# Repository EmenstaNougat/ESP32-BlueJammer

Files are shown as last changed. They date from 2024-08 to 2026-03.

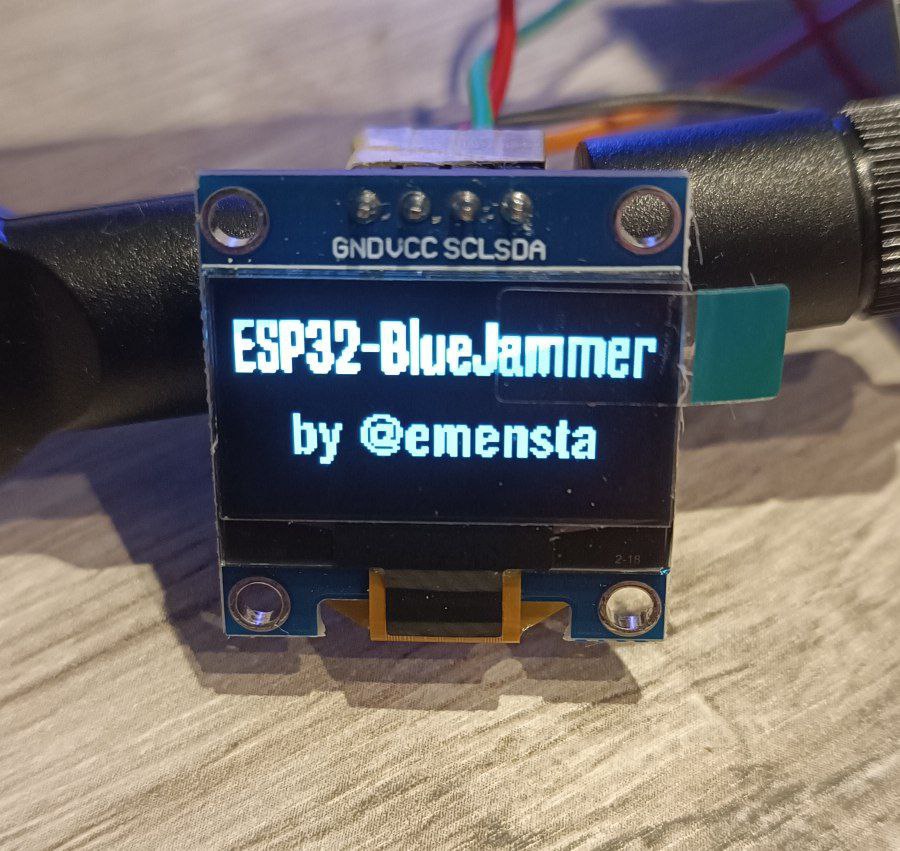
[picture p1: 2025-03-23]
Gallery/ESP32-BlueJammerOLED.jpg

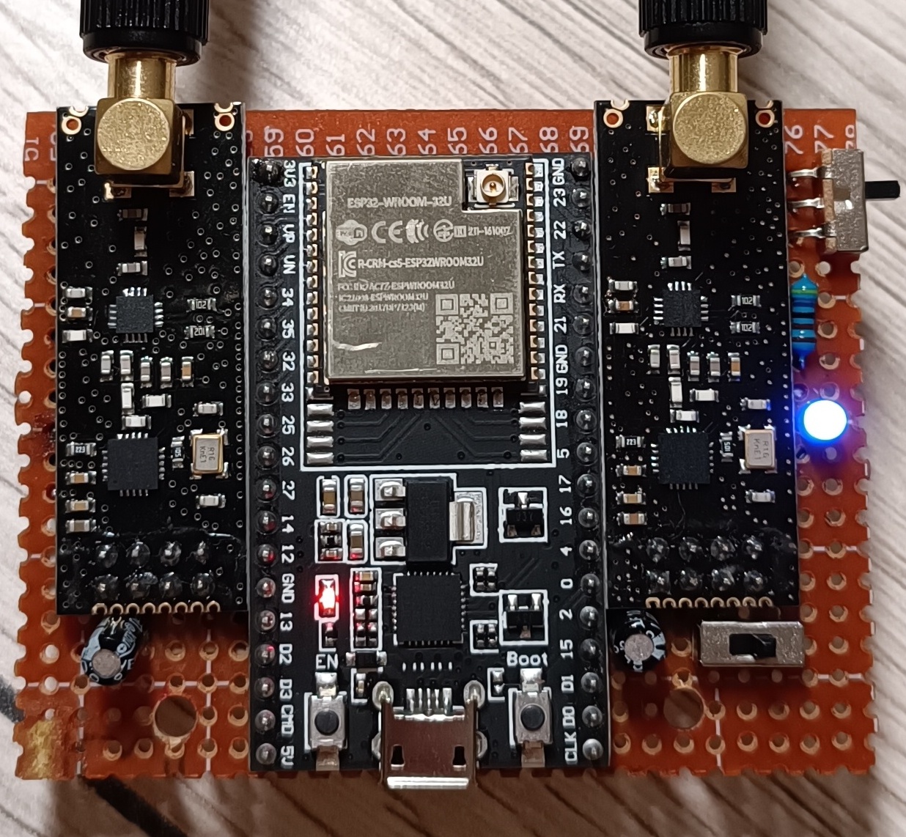
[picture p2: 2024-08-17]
Gallery/PrototypePCB.jpg

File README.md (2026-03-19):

<h1 align="center">ESP32-BlueJammer - by @emensta</h1>
<div align="center">
  ESP32-BlueJammer
  <h3 align="center">Jamming is ILLEGAL! Educational purposes only!</h3>
  <h3 align="center"><a href="https://github.com/EmenstaNougat/BlueJammer-V2">BlueJammer-V2</a>, <a href="https://github.com/EmenstaNougat/BW16-BlueJammer">BW16-BlueJammer</a> & <a href="https://github.com/EmenstaNougat/ZeroWave_FlipperZero-BlueJammer">ZeroWave for Flipper Zero</a> released!</h3>
</div>

<div align="center">
<a href="https://github.com/EmenstaNougat/ESP32-BlueJammer" title="Go to GitHub repo">
  
</a>
<a href="https://github.com/EmenstaNougat/ESP32-BlueJammer">
  
</a>
<a href="https://github.com/EmenstaNougat/ESP32-BlueJammer">
  
</a>
</div>

<h4 align="center">
  <a href="https://github.com/EmenstaNougat/ESP32-BlueJammer#hardware---make-your-own-esp32-bluejammer">Make your own</a>
    <span> | </span>
  <a href="https://github.com/EmenstaNougat/ESP32-BlueJammer#esp32-nrf24l01-pinout--battery-mod">Schematics</a>
    <span> | </span>
  <a href="https://github.com/EmenstaNougat/ESP32-BlueJammer?tab=readme-ov-file#pcb">Hardware layout</a>
    <span> | </span>
  <a href="https://github.com/EmenstaNougat/ESP32-BlueJammer?tab=readme-ov-file#pcbs-with-esp32-and-rf-module-capability">PCB's</a>
    <span> | </span>
  <a href="https://github.com/EmenstaNougat/ESP32-BlueJammer#video-tutorials-and-demonstrations">Demos</a>
    <span> | </span>
  <a href="https://github.com/EmenstaNougat/ESP32-BlueJammer#operation-channels">Channels</a>
    <span> | </span>
  <a href="https://github.com/EmenstaNougat/ESP32-BlueJammer?tab=readme-ov-file#flashing-the-firmware">Flashing</a>
    <span> | </span>
  <a href="https://github.com/EmenstaNougat/ESP32-BlueJammer#3d-printed-case">3D case</a>
    <span> | </span>
  <a href="https://github.com/EmenstaNougat/ESP32-BlueJammer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">About</a>
    <span> | </span>
  <a href="https://github.com/EmenstaNougat/ESP32-BlueJammer?tab=readme-ov-file#support-me">Support me</a>
    <span> | </span>
  <a href="https://emensta.pages.dev">Website</a>
</h4>

## ESP32-BlueJammer
The ESP32-BlueJammer (Bluetooth jammer, BLE jammer, WiFi jammer, RC jammer) disrupts various devices using an ESP32 and nRF24 modules, causing plenty of noise and sending unnecessary packets (DoS).              
                                                                    
It interrupts:  
**The whole 2.4GHz broadband!** Everything that works on 2.4GHz is being interfered, like:                                                       
audio in speakers being transmitted over bluetooth, microphones on 2.4GHz, smartphone connections, WiFi, RC Drones (etc.), IoT devices, smart gadgets, wireless keyboard & mouse, just anything on 2.4GHz!

Ideal for controlled disruption and security testing. Based on 2.4GHz communication.

It has a big range (over 30Meters+ - may vary on your antenna and hardware setup!) on newest Bluetooth versions with casual 2.4GHz antennas, you can easily increase this as well by taking some simple "bigger" router antennas.
An amplifier (2.4GHz) may be a good option too!

Remember that jamming is illegal and should not be used with malicious intent!

## PCB's with ESP32 and RF-module capability
**ESP32-RF DIY-PCB:**
This PCB can fit an ESP32-wroom-32U/E DevKitC and 2 nRF-modules, along with an 0.96" I2C OLED, LEDs and switches.  
***Remember: It is not intended for illegal use!***  
For this one, all you need is listed below:  

**Required:**  
- **[ESP32 Dev Module](https://s.click.aliexpress.com/e/_onYIVKr)** (**Recommended: ESP32-32U CP2102**, any ESP32 should work as long as it has the needed pins, 38P required!)  
- **[nRF24L01+PA+LNA](https://s.click.aliexpress.com/e/_oma5UQx)** (2x)  
- **[10-100uF Capacitor](https://s.click.aliexpress.com/e/_oFvFeYX)** (2x) (any voltage above 5V)  
- **[0.96" OLED Display I2C](https://s.click.aliexpress.com/e/_oCdkjPX)**
- **[Slide Switch](https://s.click.aliexpress.com/e/_c4eQKm5D)** (2x)
- **[LEDs: 3mm LED box](https://s.click.aliexpress.com/e/_c4dAH9sF)**  
- **[Resistor kit](https://s.click.aliexpress.com/e/_oCoJ7LO)**  
- R1 = 1kOhm  
- R2, R3, R5, R7 = 47kOhm  
- R4, R6 = 100kOhm  

**Additional:**  
- **[TP4056 Charging Module (Micro-USB/Type-C)](https://s.click.aliexpress.com/e/_oCqORHE)**  
- **[JST PH 2.0 Connector](https://s.click.aliexpress.com/e/_ooSOhDd)**  
- **[3.7V Li-Ion Battery](https://s.click.aliexpress.com/e/_on04mQ7)**  
- **[3rd Antenna: **IPEX to SMA-F pigtail](https://s.click.aliexpress.com/e/_oFDpn1V)**  
  
[Shop](https://www.elecrow.com/esp32-rf-diy-pcb.html)

---

**PRE-SOLDERED:**  "The Blue ESP"  
This is an ESP32 with RF-module breakouts (nRF24/CC1101 etc.) for experimenting.  
***Remember: It is not intended for illegal use, neither for my project!***  

**Required:**  
- **[nRF24L01+PA+LNA](https://s.click.aliexpress.com/e/_oma5UQx)** (2x)  
Why do you need to get the nRF24's? -> the pinout can be used to connect either nRF24 or CC1101 modules for further experiments with an ESP32 chip.
TheBlueESP
[Shop](https://datechlabs.com/products/the-blue-esp-pre-order)

## Video tutorials and demonstrations
[Full DIY assembling video tutorial](https://www.tiktok.com/@emensta/video/7389783018002550049)

[Full DIY assembling video tutorial (if the TikTok is not available for you)](https://www.mediafire.com/file/mgb3wicdifkq1ce/ESP32-BlueJammerByEmensta-DIYTutorial.mp4/file)

---

[Demonstration](https://vm.tiktok.com/ZGec5Mqg7/)

[Demonstration (if the TikTok is not available for you)](https://www.mediafire.com/file/xgru01ihbw26mfu/ESP32-BlueJammerByEmensta-Demonstration.mp4/file)

---

[Flashing process](https://www.tiktok.com/@emensta/video/7413509704401292577)

[Flashing process (if the TikTok is not available for you)](https://www.mediafire.com/file/2aj4hmf9zt7w6sw/ESP32-BlueJammerByEmensta-FlashingProcess.mp4/file)

---

ESP32-BlueJammer tutorial by @ElMackflay  
ESP32-BlueJammer tutorial by @ElMackflay (https://www.youtube.com/watch?v=1kjkWU25_qo)  
---

## Operation Channels
- **Bluetooth** = 79CH  
  Frequency Range: 2.402 GHz to 2.480 GHz  
  Channel Width: 1 MHz

- **BLE** = 40CH  
  Frequency Range: 2.400 GHz to 2.4835 GHz  
  Channel Width: 2 MHz

- **WiFi** = 14CH  
  Frequency Range: 2.400 GHz to 2.4835 GHz  
  Channel Width: Typically 20 MHz, but can be 22 MHz or 40 MHz in some cases

- **RC drones, etc.** = 1-125CH  
  Frequency Range: 2.400 GHz to 2.525 GHz  
  Channel Width: 1 MHz

## How to use?
To disrupt various channels on the 2.4GHz band, do the following to enable your ESP32-BlueJammer:
- Every mode starts right away after powering on the device! There is no additional button to start the attack!  
- It simply jams right away once powered!

### Combo-Channel-Select_BT-BLE-WiFi-RC firmware:
- use the "Boot" button on the ESP32 to switch between the channel modes on the Combo-Firmware!
- the OLED will display your current operation channel
- the status LED lets you know about the current state you're in:  
1 blink = BT  
2 blinks = BLE  
3 blinks = WiFi  
4 blinks = RC  
- the serial output of your ESP32-BlueJammer will output the following lines when switching mode:  
State 1: Bluetooth  
State 2: Bluetooth Low Energy  
State 3: WiFi  
State 4: RC  

### all other firmware:
- the firmware you choose indicates the operation channel by its name, this means:

Bluetooth_80_CH - jams classic Bluetooth  
Frequency Range: 2.402 GHz to 2.480 GHz  

BluetoothLowEnergy_40_CH - jams Bluetooth Low Energy  
Frequency Range: 2.400 GHz to 2.4835 GHz  

Bluetooth-BluetoothLowEnergy_40-80_CH - jams classic Bluetooth & Bluetooth Low Energy  
Frequency Range: 2.402 GHz to 2.480 GHz & 2.400 GHz to 2.4835 GHz  

Bluetooth-WiFi_14-80_CH - jams classic Bluetooth & WiFi  
Frequency Range: 2.402 GHz to 2.480 GHz & 2.400 GHz to 2.4835 GHz  

WiFi_14_CH - jams WiFi  
Frequency Range: 2.400 GHz to 2.4835 GHz  

2.4GHzRemoteControl(Drones etc.)_1-125_CH - jams RC (Drones etc.)  
  Frequency Range: 2.400 GHz to 2.525 GHz  

## Hardware - Make your own ESP32-BlueJammer
(Aliexpress affiliate links to support me-linked to the item names)
### Required:

- **[ESP32 Dev Module](https://s.click.aliexpress.com/e/_onYIVKr)** (**Recommended: ESP32-32U CP2102**, any ESP32 should work as long as it has the needed pins)
- **[nRF24L01+PA+LNA](https://s.click.aliexpress.com/e/_oma5UQx)** (2x)
- **[10-100uF Capacitor](https://s.click.aliexpress.com/e/_oFvFeYX)** (2x) (any voltage above 5V)
- **[Prototype PCB](https://s.click.aliexpress.com/e/_oBtd18j)** (at least 7x9 cm, but you will need to cut it down to fit the 3D-printed case, which fits a size of 7x5,5cm!)

### Additional:

- **[0.96" OLED Display I2C](https://s.click.aliexpress.com/e/_oCdkjPX)**
- [3rd Antenna: **IPEX to SMA-F pigtail**](https://s.click.aliexpress.com/e/_oFDpn1V)
- [Status LED: **3mm LED**](https://s.click.aliexpress.com/e/_ooxufHV)
- **[4.7k Ohm Resistor](https://s.click.aliexpress.com/e/_oBV1Q1Z)**

### If you're looking to add a battery:

- **[3.7V Li-Ion Battery](https://s.click.aliexpress.com/e/_on04mQ7)**
- **[JST PH 2.0 Connector](https://s.click.aliexpress.com/e/_ooSOhDd)**
- **[TP4056 Charging Module (Micro-USB/Type-C)](https://s.click.aliexpress.com/e/_oCqORHE)**
- **[Mini Slide Switch](https://s.click.aliexpress.com/e/_ooC8DXh)**

### To screw the 3D printed case together you must have:

- **M3x16 Screws** (2x)  
- **M3 Nuts** (2x)  
Get this M3 kit instead:
- **[M3 screws&nuts kit](https://s.click.aliexpress.com/e/_oC24YXH)**

## Antennas
A frequently asked question is whether the antennas are needed and what the third antenna is for, here is the answer:
Yes, you need at least both antennas for the nRF24's! Why? To have it working on a decent range!
The average range with standard known chinese 2.4GHz antennas is about 20-30meters. Upgrading those antennas will help a lot with getting more range!

2 antennas are for the HSPI and VSPI nRF24 modules!

The 3rd antenna is plugged to the ESP32 chip itself, whether via IPEX or soldered onto its own antenna, if your ESP32 does not provide any option to add that one, it obviously won't be possible!
What is the 3rd antenna used for? The third antenna connected to the ESP32 chip itself helps with reliable long-range interference. It ensures a better intermediate signal and stability when jamming!
(The third antenna is your own decision and therefore optional!)

## Flashing the firmware
### via webflasher (Easy)  
ESP32-BlueJammerFlasher                                                                 
I've created a webflasher to make it super easy for you to flash your ESP32 chip with the ESP32-BlueJammer firmware of your choice!  
- Visit [ESP32-BlueJammerFlasher](https://esp32-bluejammerflasher.pages.dev)
- First, choose the firmware type, "Generic" or "0.96" OLED"
- choose the firmware you want to flash
- Connect your ESP32 via a data USB cable
- Flash the firmware of your choice :D

### Flashing ESP32 via binary files (Advanced)  
- Download the **.bin files** available on this repository
- Use any flasher of your choice
- Flash it :D

If your ESP32 is not showing up in the device list or won't get recognized you will need to have [THESE DRIVERS INSTALLED](https://www.silabs.com/documents/public/software/CP210x_Windows_Drivers.zip) which can be found on my [Discord server](https://discord.gg/yNGhKxzqUE) too!

## ESP32-nRF24L01+ pinout + battery mod
Here are both pinouts for HSPI and VSPI. You need both nRF24L01 modules connected in order to achieve full capability of the device.                
[nRF24L01+ pinout](https://dwdwpld.pages.dev/nRF24L01pinout.png)
### HSPI
| 1st nRF24L01 module Pin | HSPI Pin (ESP32) | 10uf capacitor |
|---|---|---|
| VCC | 3.3V | (+) capacitor |
| GND | GND | (-) capacitor |
| CE | GPIO 16 |
| CSN | GPIO 15 |
| SCK | GPIO 14 |
| MOSI | GPIO 13 |
| MISO | GPIO 12 |
| IRQ | |

### VSPI 
| 2nd nRF24L01 module Pin | VSPI Pin (ESP32) | 10uf capacitor |
|---|---|---|
| VCC | 3.3V | (+) capacitor |
| GND | GND | (-) capacitor |
| CE | GPIO 22 |
| CSN | GPIO 21 |
| SCK | GPIO 18 |
| MOSI | GPIO 23 |
| MISO | GPIO 19 |
| IRQ | |

### Status LED
| ESP32 | 4.7k Ohm Resistor | 3mm Status LED (blue)|
|---|---|---|
|  GND  | | (-) LED |
| | Resistor | (+) LED |
|GPIO27 | Resistor | |

### OLED Display I2C (additional - make sure to use the correct firmware!)
| 0.96" OLED Display I2C | ESP32 |
|---|---|
| GND |  GND  |
| VCC | 3.3V  |
| SCL |GPIO 5 |
| SDA |GPIO 4 |

### Battery modification (additional)
| 3.7V Li-Ion battery | JST-PH2 connector | TP4056 Charging Module | Mini Slide Switch | ESP32 |
|---|---|---|---|---|
| (+) Battery | (+) JST-PH2 | Bat + | | |
| (-) Battery | (-) JST-PH2 | Bat - | | |
| | | OUT + | Switch in | |
| | | OUT - | |  GND  |
| | | | Switch out |  3V3  |

## PCB

<h3 align="center">That's how the components are placed (PCB size=7cm x 5.5cm - Larger sizes will NOT fit in the case!)</h3>

DIYPCB

## 3D printed case
#### The 3D printed case fits ONLY a PCB size of 7cm x 5.5cm and you'll need to drill out 2 holes according for the M3 screws to fit through the PCB!
<h3 align="center">Access to the ESP32 micro-USB port, as well as to both EN & Boot buttons</h3>

ESP32MicroUSB

<h3 align="center">TP4056 charging port access with charging state indicator holes (red=charging - blue=fully charged)</h3>

USB_C_chargerWithIndicators

<h3 align="center">On/off switch with blue indicator LED</h3>

OnOffSwitch

## V3-Case 3D model view [[download .stl](https://dwdwpld.pages.dev/V3-ESP32-BlueJammerBy@emensta3DCase.stl)]

<h3 align="center">Here's a look at the V3 2 antenna version itself</h3>

3DCaseView

## V4-Case 3D model view [[download .stl](https://dwdwpld.pages.dev/V4-ESP32-BlueJammerBy@emensta3DCase.stl)]

<h3 align="center">Here's a look at the V4 3 antenna version itself</h3>

3DCaseView

## About the ESP32-BlueJammer and my source code
- **Is my ESP32-BlueJammer really working?**  
  Yes! My ESP32 BlueJammer is fully functional, and no one pauses the sound in the demo video. Many people have built their own ESP32-BlueJammer and confirmed that it works! Join my Discord and see for yourself! ;D

- **Why my ESP32-BlueJammer code is NOT open source**  
  There are several "BLE Jammers" available on GitHub, but they all have limitations in frequency range, channel coverage, and effective distance (around 5 meters). Therefore I decided to develop and code my own firmware for the ESP32-BlueJammer, aiming for superior performance.

  Despite some claims that I might have copied someone else's work, it's important to clarify that extracting source code from a compiled file (.hex, .bin, etc.) is practically impossible. If I had used someone else's work, I wouldn't have been able to create custom console banners, develop multiple firmware versions, or build a web flasher. My code is entirely written from scratch. There is nothing taken from other available codes, sources, codebases or resources as a foundation, if any even exist. My code remains closed source for now, to protect the significant effort and innovation I've invested in this project.

  This isn't my last project. I'm looking forward to implementing the ESP32-BlueJammer in further ongoing projects, so for now, I'd like the code to remain closed source. Maybe someday I'll make it open source!  
  -no one knows. ;D
## Source code snippets by @emensta
- **Here are three snippets of my source code for you to compare with other available sources. This way, you can see that it was written from scratch:** 
ESP32-BlueJammerByEmenstaCodeSnippets

## Discord
You can join my Discord server [here](https://discord.gg/emensta)!

## Portfolio and all my links
Here you can visit my Portfolio, you'll find everything that you're looking for [here](https://emensta.pages.dev)!

## Support me
Via [this link](https://ko-fi.com/emensta), you can leave a tip to keep me motivated developing future projects! Thank you for your support :)

<h1 align="center"> DISCLAIMER </h1>

<h4 align="center">Please note that the use of this tool is entirely at your own risk. It is intended strictly for educational purposes and should not be used for any illegal or unethical activities. Jamming is illegal and can get you in big trouble!</h4>
<h4 align="center">I'm not responsible for your actions! </h4>

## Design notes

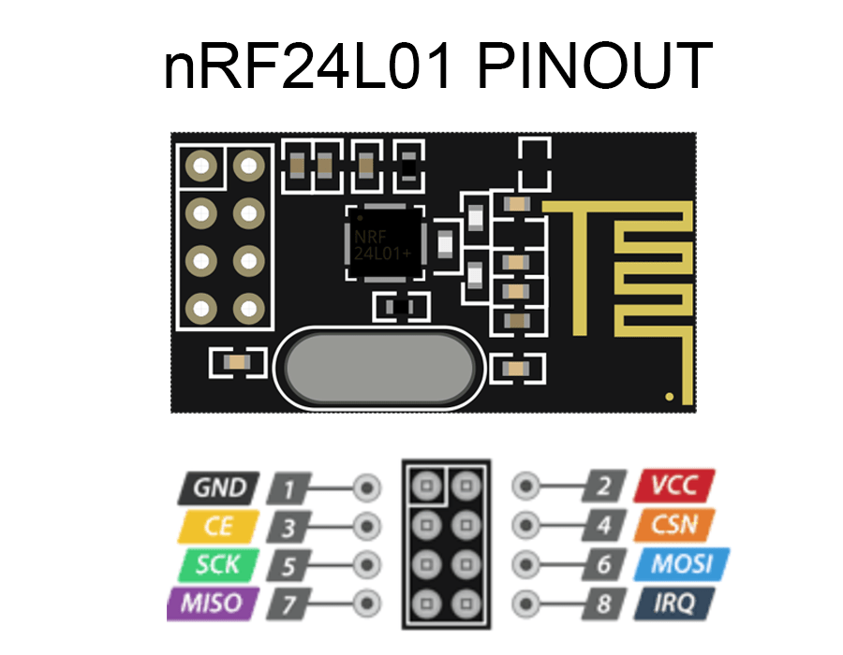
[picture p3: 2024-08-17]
Gallery/nRF24L01pinout.png

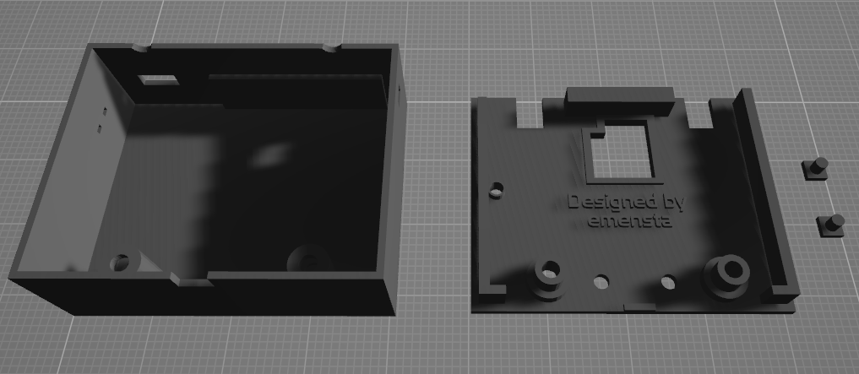
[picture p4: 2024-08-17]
Gallery/V3-ESP32-BlueJammer3DCaseView.png

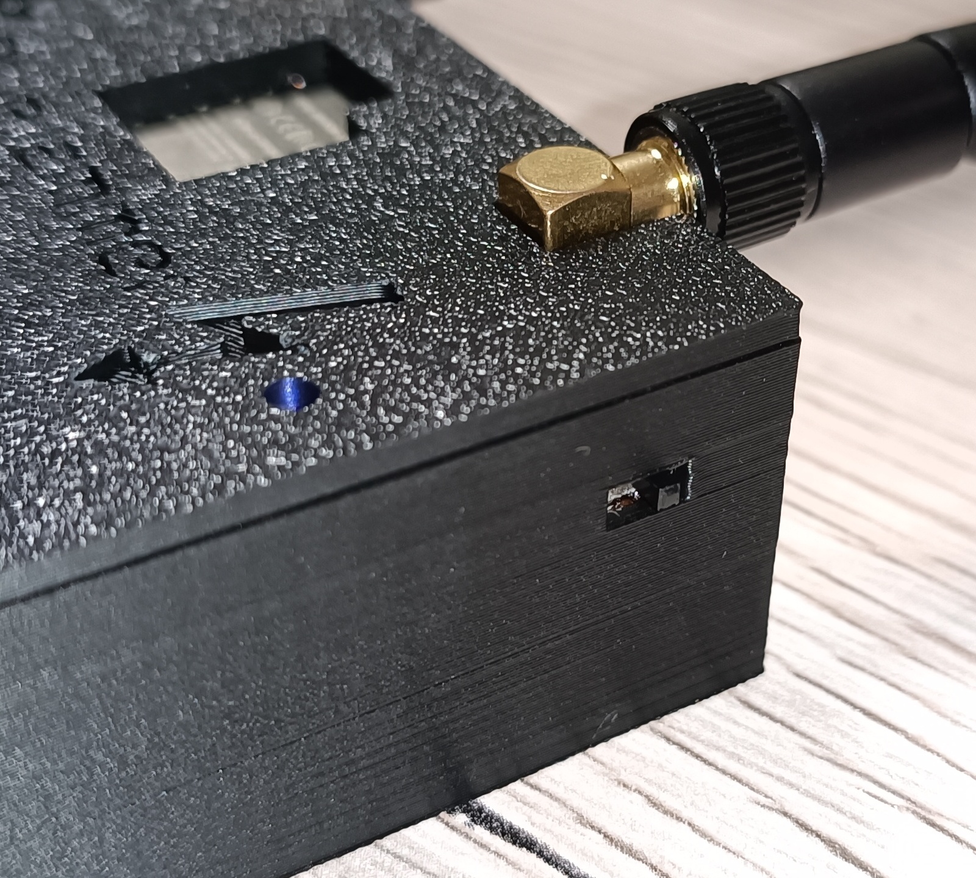
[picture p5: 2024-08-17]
Gallery/ESP32-BlueJammerOnOffSwitch.jpg

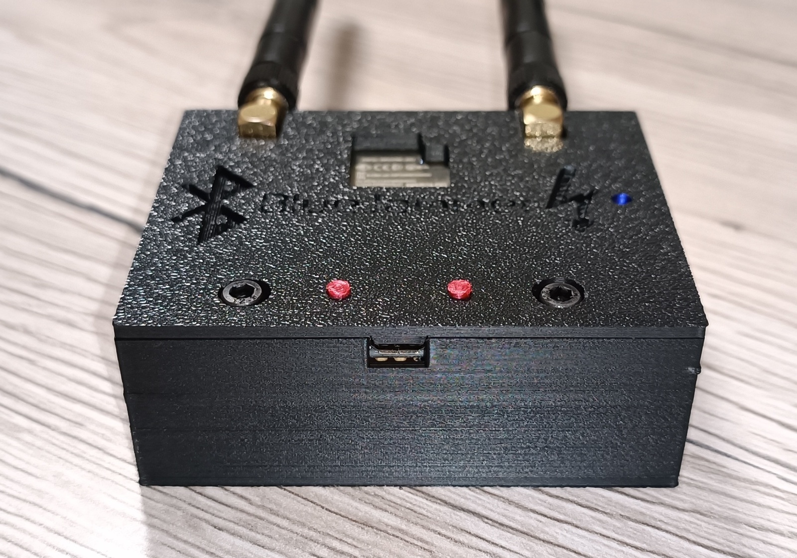
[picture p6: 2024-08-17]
Gallery/ESP32-BlueJammerMicroUsb.jpg

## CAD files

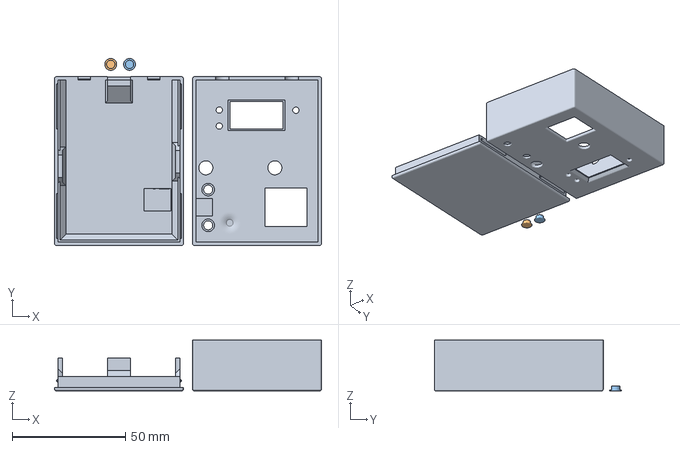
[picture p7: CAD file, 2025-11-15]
3D files/ESP32-RF_DIY-PCB_enclosure/ESP32-RF_DIY-PCB_enclosure.3mf
117.8 x 82.6 x 22.5 mm
Zusammenbau
BTN x 2

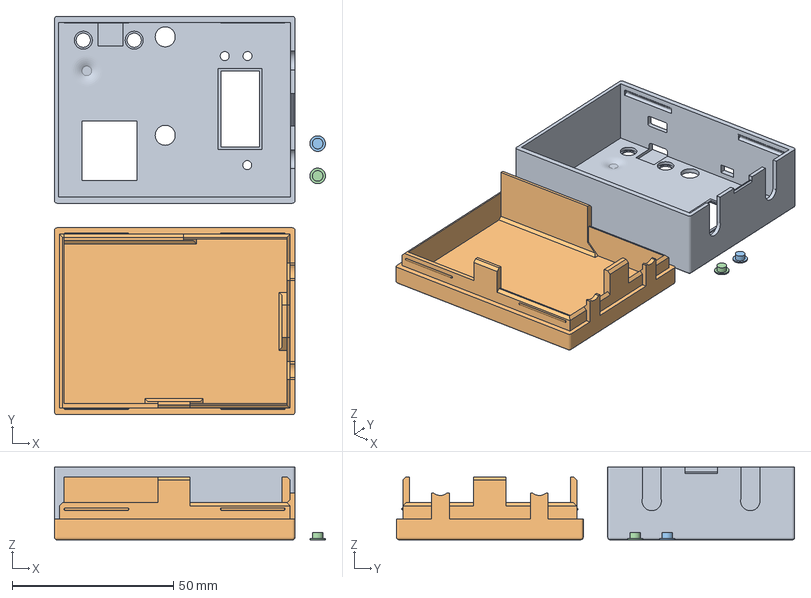
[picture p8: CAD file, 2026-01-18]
3D files/ESP32-RF_Ebyte_DIY-PCB_enclosure/ESP32-RF_Ebyte_DIY-PCB_enclosure.3mf
83.9 x 123.4 x 22.5 mm
ESP32-RF_DIY-PCB_Top.stl
ESP32-RF_DIY-PCB_Bottom.stl
ESP32-RF_DIY-PCB_Button.stl x 2

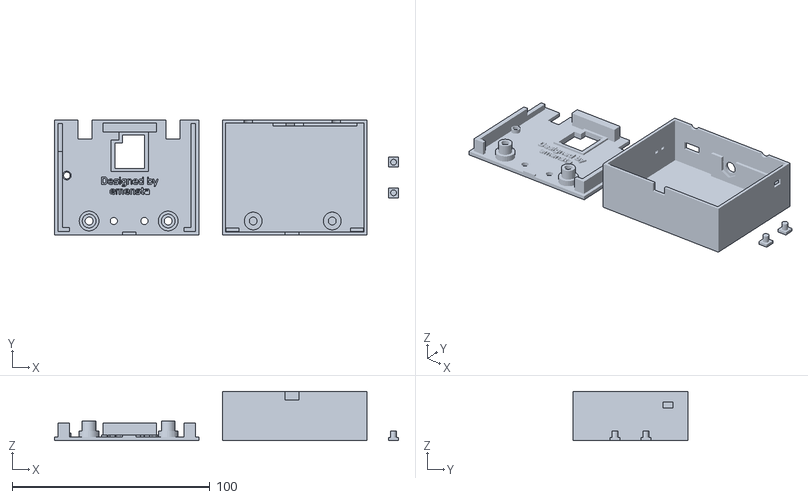
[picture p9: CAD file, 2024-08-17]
3D files/PerfboardBuild/V4-ESP32-BlueJammerBy@emensta3DCase.stl
174.0 x 58.0 x 25.0

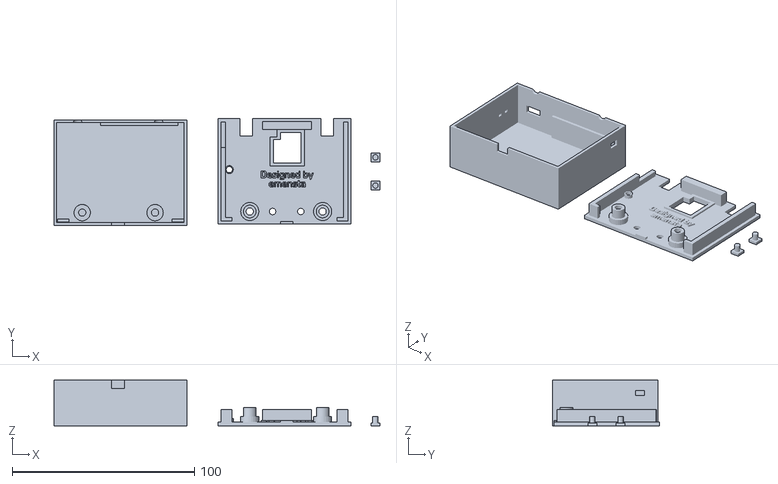
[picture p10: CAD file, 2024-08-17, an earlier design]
3D files/PerfboardBuild/V3-ESP32-BlueJammerBy@emensta3DCase.stl
179.0 x 58.6 x 25.0

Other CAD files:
3D files/ESP32-RF_DIY-PCB_enclosure/ESP32-RF_DIY-PCB_enclosure.stl
3D files/ESP32-RF_Ebyte_DIY-PCB_enclosure/ESP32-RF_Ebyte_DIY-PCB_enclosure.stl

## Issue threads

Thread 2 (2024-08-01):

HSPI nRF24 module could NOT be initialized! error after installation

Max24341, 2024-08-01:
i soldered everything according to the pinout. double checked everything but it doesnt work.
the YSPI part works, but the HSPI doesnt.
im using a ESP32 Wroom 32D

this is the boot:

E (152) wifi_init: Failed to deinit Wi-Fi driver (0x3001)
!!! HP (high power) start failure! HSPI nRF24 module could NOT be initialized! ~~~~~~~~~~~~~~~~~~~~
╦  ╦╔═╗╔═╗╦
╚╗╔╝╚═╗╠═╝║
 ╚╝ ╚═╝╩  ╩

SP Started !!! VSPI nRF24 module initialized successfully! ~~~~~~~~~~~~~~~~~~~~
SPI Frequency		= 16 Mhz
Channel			= 76 (~ 2476 MHz)
Model			= nRF24L01+
RF Data Rate		= 2 MBPS
RF Power Amplifier	= PA_MAX
RF Low Noise Amplifier	= Enabled
CRC Length		= Disabled
Address Length		= 5 bytes
Static Payload Length	= 32 bytes
Auto Retry Delay	= 250 microseconds
Auto Retry Attempts	= 0 maximum
Packets lost on
    current channel	= 0
Retry attempts made for
    last transmission	= 0
Multicast		= Disabled
Custom ACK Payload	= Disabled
Dynamic Payloads	= Disabled
Auto Acknowledgment	= Disabled
Primary Mode		= TX
TX address		= 0xffffffffff
pipe 0 ( open ) bound	= 0xe7e7e7e7e7
pipe 1 ( open ) bound	= 0xc2c2c2c2c2
pipe 2 (closed) bound	= 0xc3
pipe 3 (closed) bound	= 0xc4
pipe 4 (closed) bound	= 0xc5
pipe 5 (closed) bound	= 0xc6

EmenstaNougat, 2024-08-01:
Obviously your HSPI is not wired correctly physically or it's defect. Check everything, that's not an firmware issue.

Max24341, 2024-08-01:
> Obviously your HSPI is not wired correctly physically or it's defect. Check everything, that's not an firmware issue.

i had double checked everything, when i switch it the modules around it works. but it seems that just the HSPI is just not working

EmenstaNougat, 2024-08-01:
Then you should check another nrf on it's position

Closed 2024-08-02.

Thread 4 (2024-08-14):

Improve range

BannanaWithZipper, 2024-08-14:
Hello,

Has anybody experimented with improving the range? I am getting lost while searching for an antenna that has more range that the standard antennas that come with the nRF24L01+PA+LNA.
 Do I need more dbi? a bigger antenna? Would the antennas from a laptop be  of any good?
 A link to a specific product, ex amazon or even better AliExpress would be highly appreciated.
What I found and thought of buying is "SAVIO Omnidirectional WiFi 12dBI 41CM RP-SMA AK-05"
https://www.savio.net.pl/en/product/savio-omnidirectional-wifi-antenna-12dbi-41cm-rp-sma-ak-05/

webportpl, 2024-08-30:
https://www.nordicsemi.com/Products/nRF24-series

EmenstaNougat, 2024-08-30:
You need a higher dbi value, but it's a directional antenna, therefore you must target the device you want to jam

Closed 2024-08-30.

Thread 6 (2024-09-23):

30 pin

Lgndwilloske, 2024-09-23:
Will a 30 pin esp work??

EmenstaNougat, 2024-09-23:
Hardware
Required:
ESP32 Dev Module (such as ESP32-WROOM-32U, any ESP32 should work as long as it has the needed pins!)
nRF24L01+PA+LNA (2x)
10uF Capacitor (2x) (any voltage above 5V)
Additional:
3rd Antenna: IPEX to SMA-F pigtail
Status LED: 3mm LED
4.7k Ohm Resistor
If you're looking to add a battery:
3.7V Li-Ion Battery
JST PH 2.0 Connector
TP4056 Charging Module (Micro-USB/Type-C)
Mini Slide Switch

Lgndwilloske, 2024-09-23:
so im guessing its a no then

Closed 2024-09-28.

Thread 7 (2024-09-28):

bread board

Lgndwilloske, 2024-09-28:
would i be able to use a breadboard for this instead? I cant seem to solder it, every time i do it and i plug it in it just smokes and breaks. Also when i flash it with the firmware it doesent jam anything?
 Thanks

Closed 2024-09-28.

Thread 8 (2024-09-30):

10uf capacitors

cabralcr, 2024-09-30:
Hello, first of all I would like to thank you for the project, one question, what is the function of the two 10uf capacitors, wouldn't it be better to put just one of 22uf? since they are on the same 3.3v and gnd line.

Asmodeux2, 2024-10-08:
> Здравствуйте, прежде всего я хотел бы поблагодарить вас за проект, один вопрос, какова функция двух конденсаторов по 10 мкФ, не лучше ли поставить один на 22 мкФ? Так как они находятся на одной линии 3,3 В и земли.

Конденсатор нужен для стабильного запуска nrf24l01+pa+lna. Есть большое количество данных что напряжение просидает и он переходит в режим PD [Power Down] и а так конденсатор выступает в качестве фильтра.

Asmodeux2, 2024-10-08:
> Здравствуйте, прежде всего я хотел бы поблагодарить вас за проект, один вопрос, какова функция двух конденсаторов по 10 мкФ, не лучше ли поставить один на 22 мкФ? Так как они находятся на одной линии 3,3 В и земли.

В случае использования 22 мкФ нужно учесть что напряжение может пойти на один модуль а не разделиться и направится в два модуля. И от этого они умрут. [Напряжение выше 3.6V уже критично для nrf24l01]

Closed 2024-10-13.

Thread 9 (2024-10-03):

Remote Control

basgti1862, 2024-10-03:
Hey it would be nice when you can add an remote control.

Maybe so its opening a Wifi connection and when you connect with a random password you can access a site and Control it

EmenstaNougat, 2024-10-13:
Not possible unfortunately, if you would start jamming, you would jam the connection between the ESP32-BlueJammer and your phone, therefore you will need to turn it off by yourself again

Closed 2024-10-13.

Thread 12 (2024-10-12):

One way amplifier

MrTalon63, 2024-10-12:
Does the firmware RX any data on NRF's or ESP32 antenna ports? I have multiple 2.4GHz one way amplifier I want to test out with this project.

Asmodeux2, 2024-10-13:
You can safely test the amps, it's been done before and the results are great!

Closed 2024-10-31.

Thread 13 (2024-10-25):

Problem with low range

JairoMsj, 2024-10-25:
I correctly followed the hardware acquisition. I carried out the assembly without the battery, but as per the instructions. I installed the firmware, as instructed, but the Bluetooth blocking range did not exceed 4 meters. What could have gone wrong?

EmenstaNougat, 2024-10-31:
It has to be the wiring, several people on the Discord made it recently and it's working. Wiring or hardware

Closed 2024-10-31.

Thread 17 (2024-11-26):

Short range

pikachu2010, 2024-11-26:
Hi guys

I have made this bluetooth jammer but the range is only 1 or 2 meters.
What is the problem here?
I use the antennas that came use the module and i have also high gain antennas but is still a few meter 2 or 3.

biscuitaep, 2024-12-01:
Are you using LNA+PA module?
And which esp32

EmenstaNougat, 2024-12-01:
It has to be the wiring, poeple have fixed such issues by resoldering, and they've had a shortened pin. Averagre range should be 30m

Closed 2024-12-07.

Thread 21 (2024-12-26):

HELP

3440715446, 2024-12-26:
Why is my ESP32 indicating module installation failure？
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

Le0nyx, 2024-12-26:
Could you give further details, like from where you get the error, when the error happens and such. It could be a driver issue if you are running windows or based on you saying installation issue it could be when you upload that the sketch won't upload since the esp refuses connection. For this press the boot button until it is uploading with the % on the webflasher or the loadingbar in Arduino IDE with the ... is past that.

3440715446, 2024-12-28:
This is the video I uploaded, please help me identify it

3440715446, 2024-12-28:
Following your instructions, I held down the boot button and released it when prompted with%. Then, I checked the logs and found that the module installation failed. I think it's because my ESP module model is incorrect. Below is the log of the error I reported during installation
[esp-web-tools-logs.txt](https://github.com/user-attachments/files/18265060/esp-web-tools-logs.txt)

3440715446, 2024-12-28:
> Could you give further details, like from where you get the error, when the error happens and such. It could be a driver issue if you are running windows or based on you saying installation issue it could be when you upload that the sketch won't upload since the esp refuses connection. For this press the boot button until it is uploading with the % on the webflasher or the loadingbar in Arduino IDE with the ... is past that.

Following your instructions, I held down the boot button and released it when prompted with%. Then, I checked the logs and found that the module installation failed. I think it was because my ESP module model was incorrect. Below is the log of the error I reported during installation. The video has been accelerated

Uploading _屏幕录制20241228132857.mp4…

3440715446, 2024-12-28:
Uploading _屏幕录制20241228132857.mp4…

3440715446, 2024-12-28:
Uploading _屏幕录制20241228132857.mp4…

3440715446, 2024-12-28:
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

3440715446, 2024-12-28:
Uploading _屏幕录制20241228132857.mp4…

Le0nyx, 2024-12-28:
I have a similar ESP32 module so the chip itself should not be the issue. Sadly I am not able to see the video you seem to have uploaded for some reason (Might be an issue from side of Github not supporting videos). Do you have the drivers installed so the ESP32 actually shows up? If not let's try to upload a simple Sketch from Arduino IDE to the ESP. Download the ESP32 library in Arduino IDE and check the COM-Ports if the ESP shows up. If not install the necessary drivers. If it does show up try uploading a Sketch and press while the terminal says connecting the boot button on the ESP. To choose which model search for "ESP32 Dev Module". With this Sketch the built in LED on the ESP32 should blink (Define the correct Pin depending on the ESP you own):

---

// Define the onboard LED pin
// ESP8266: Built-in LED is typically on GPIO2 (D4 on NodeMCU)
// ESP32: Built-in LED is typically on GPIO2 or GPIO13
#if defined(ESP8266)
  const int LED_PIN = 2; // Change if your module has a different LED pin
#elif defined(ESP32)
  const int LED_PIN = 2; // Commonly GPIO2 or GPIO13, adjust as needed
#else
  #error "Unsupported board"
#endif

void setup() {
  // Initialize the LED pin as an output
  pinMode(LED_PIN, OUTPUT);
}

void loop() {
  // Blink the LED
  digitalWrite(LED_PIN, HIGH); // Turn the LED on
  delay(500);                  // Wait for 500 ms
  digitalWrite(LED_PIN, LOW);  // Turn the LED off
  delay(500);                  // Wait for 500 ms
}

3440715446, 2024-12-29:
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
I followed your instructions and uploaded two codes with different pins to ESP32, but unfortunately, there is no sign of LED flashing in my module in reality. I don't understand where the problem lies

3440715446, 2024-12-29:
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
According to your suggestion, I have uploaded the code for the built-in LED light flashing through Arduino IDE. It is exciting that it is indeed flashing in practice, which proves that it is not a problem with the driver. Therefore, what is the reason why I cannot install the firmware for this bluehammer

3440715446, 2024-12-29:
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
My error message shows that I am not currently connected to nRF24L01+PA+LNA

Le0nyx, 2024-12-29:
Great to hear. Glad I could provide some help/ hope. Happy tinkering!

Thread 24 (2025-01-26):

Poor performance

aguywithagithubaccount, 2025-01-26:
Extremely poor performance, 2 nrf's and the caps installed, 10cm range

EmenstaNougat, 2025-01-26:
You have made something wrong, not possible to get such a range with everything connected properly. Join discord for wuicker problem solving

sturby1, 2025-01-29:
I did mine exactly like yours but it's not working at all, I checked the voltage between the connections and it gave me 0.5V striaght out of the ESP32, do you have any idea what I'm doing worng?

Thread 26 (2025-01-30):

RC Jamming Not Working

isamsel, 2025-01-30:
To be very clear, in my build of this project, the Bluetooth and 2.4GHz WiFi jamming capabilities are EXCELLENT. Both range and robustness far exceeded my expectations and anyone claiming it just doesn't work has clearly done something incorrectly.
However, the functionality I was most excited about was the capability to jam RC car signals. I tested this functionality with the same build that has great performance otherwise and it had absolutely no effect. I don't have any model names, but I tested this functionality with at least 4 modern RC cars/radios from my dad's ample collection.

I'm enthusiastic about this project because I love introducing this flavor of chaos into the world. Because of that (and my experience in programming and electrical circuits) I would be more than happy to help debug this portion of the project, but obviously that's not exactly possible as long as the code is a black box.

Have you had any other knows issues jamming RC/Drone devices and/or would you consider allowing some outside help debugging?

EmenstaNougat, 2025-01-30:
Very happy about your feedback! :)
You should check up on the frrquencies the RC cars etc. run on. Most of them use 27mhz, There have been uploads on TikTok demonstrating it, and it jammed the signal successfully, same for me testing it on a toy drone. Make sure it's 2.4GHz, I will have another look at it the next days :)

isamsel, 2025-01-31:
I can confirm that each model I tested on had a 2.4GHz radio; I checked them all myself.
But perhaps I can think of one question that might help narrow down the issue. Which antenna(s) should be carrying the signal intended for RC and Drone jamming? On odd thing I noticed is that I never see any output from the ESP-32 ("center") antenna, which does make me wonder if there's a problem with the RF section of the microcontroller in my build (which obviously wouldn't have anything to do with your software).
I should probably describe my setup to explain what I mean by that. My build includes the standard components purchased on Amazon; the ESP-32 and NRF24l01s are all connected to identical WiFi antennas (with correct SMA connector polarity). It's flashed with the all-in-one version of your firmware (WiFi + BT + BTLE + RC/Drone). I don't have a scope anywhere near fast enough to measure a 2.4GHz signal, but I wanted to get some relative power output measurements to gauge the quality of some RF amps I got on Amazon, so I hooked an envelope detector up to another WiFi antenna to make a crude 2.4GHz "sensor." This allows me to see when each individual antenna is outputting signal and get a rough estimate of the power levels, and based on the output from the NRF24l01s it seems to work quite well.
I had also tried flashing the ESP-32 with the RC/Drone-only version of the firmware, and while I didn't test this build on any actual cars or drones, I did look at the signal output of the antennas with the envelope detector. I never saw signal coming from any antenna with that version of the firmware, which is why I went back to the all-in-one version.

pablopeu, 2025-02-03:
Most ESP32 with antenna connectors aren't connected to the antenna connector by default, you have to remove a 0 ohm resistor (a bridge) and put it between two pads that route to the antenna connector (or a solder blob).

isamsel, 2025-02-04:
Unfortunately, I believe you're thinking of the ESP32-CAM, or at least boards that have both a PCB antenna AND an IPEX connector. I'm using the version of the ESP32-WROOM-32U that has ONLY the IPEX connector.

pablopeu, 2025-02-04:
it was worth the shoot, hope you solve it

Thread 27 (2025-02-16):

Gatekeeping Source Code is Crazy

YeetTheAnson, 2025-02-16:
As per the title, why even bother using git if it's not open sourced?

EmenstaNougat, 2025-02-16:
So why are you here then if it does not fit you?

jamieduke, 2025-02-26:
Because you're an idiot who is gatekeeping source code on github 🤣

alias-kenny, 2025-02-26:
> Because you're an idiot who is gatekeeping source code on github 🤣
>

Probably copied https://github.com/cifertech/RF-Clown

Who knows.

EmenstaNougat, 2025-02-26:
Just look at the release date and at the files, I have not changed them ;D
Y'all first gotta think, then call out others "idiots"

Kenny White ***@***.***> schrieb am Mi., 26. Feb. 2025, 04:38:

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

Closed 2025-02-26.

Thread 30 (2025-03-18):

Does this work for wireless microphones?

TRSinan4093, 2025-03-18:
Hello, is this project jamming wireless microphones?

EmenstaNougat, 2025-03-20:
as long as theyre on 2.4GHz. yes. anything on 2.4GHz is affected

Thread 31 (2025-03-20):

VSPI (standard power) start failure! VSPI nRF24 module could NOT be initialized!

quochung2310, 2025-03-20:
Hi, I tried all steps follow your instruction, purchased the same modules, but only HSPI module work.

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

This is parts I bought:

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

I have checked carefully, swap between modules, bought another modules, but only HSPI worked.
I thought maybe there is something wrong with ESP32 pin, but I don't know how to check.

Any suggestion please?

EmenstaNougat, 2025-03-20:
It's a simple wiring issue, hop on over to Discord for some help

Arthy71, 2025-03-20:
DISCORD LINK NOT WORKING

EmenstaNougat, 2025-03-21:
https://discord.gg/8M6XBR9X

quochung2310, 2025-03-25:
Discord link isn't valid, anything else I could do?

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

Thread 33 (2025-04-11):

Alternative PCB supplier

brandonfake69, 2025-04-11:
Any alternatives to DA Tech Labs pcb? They have been out of stock for quite some time and I get no response.

EmenstaNougat, 2025-04-11:
For now, it would only be available at DaTechLabs. Maybe in thr future there would be an alternaltive link.

EmenstaNougat, 2025-07-30:
Hi, now PCBs to solder are available here:
https://www.elecrow.com/marketplace/seller/collection/shop/Emensta

Not pre-solderes tho!

Closed 2025-04-25.

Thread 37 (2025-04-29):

Log no error but nothing happens

khang238vu, 2025-04-29:
I flashed the "Combo-Channel-Select (BT-BLE-WiFi-RC)" version, connected the right wires, and the log no error
```
╦  ╦╔═╗╔═╗╦       ╔═╗╦ ╦╔═╗╔═╗╔═╗╔═╗╔═╗
╚╗╔╝╚═╗╠═╝║  ───  ╚═╗║ ║║  ║  ║╣ ╚═╗╚═╗
 ╚╝ ╚═╝╩  ╩       ╚═╝╚═╝╚═╝╚═╝╚═╝╚═╝╚═╝

SP (standard power) started !!! VSPI nRF24 module initialized SUCCESSFULLY! ########################################################

SPI Frequency		= 16 Mhz
Channel			= 76 (~ 2476 MHz)
Model			= nRF24L01+
RF Data Rate		= 2 MBPS
RF Power Amplifier	= PA_MAX
RF Low Noise Amplifier	= Enabled
CRC Length		= Disabled
Address Length		= 5 bytes
Static Payload Length	= 32 bytes
Auto Retry Delay	= 250 microseconds
Auto Retry Attempts	= 0 maximum
Packets lost on
    current channel	= 0
Retry attempts made for
    last transmission	= 0
Multicast		= Disabled
Custom ACK Payload	= Disabled
Dynamic Payloads	= Disabled
Auto Acknowledgment	= Disabled
Primary Mode		= TX
TX address		= 0xffffffffff
pipe 0 ( open ) bound	= 0xe7e7e7e7e7
pipe 1 ( open ) bound	= 0xc2c2c2c2c2
pipe 2 (closed) bound	= 0xc3
pipe 3 (closed) bound	= 0xc4
pipe 4 (closed) bound	= 0xc5
pipe 5 (closed) bound	= 0xc6

~~~~~~~~~~~~~~~~~~~~~~~~~~~~~~~~~~~~~~~~~~~~~~~~~~~~~~~~~~~~~~~~~~~~~~~~~~~~~~~~~~~~~~~~~~~~~~~~~~~~~~~~~~~~~~~~~~~~~~~~~~~~~~~~~~~~

╦ ╦╔═╗╔═╗╦       ╔═╗╦ ╦╔═╗╔═╗╔═╗╔═╗╔═╗
╠═╣╚═╗╠═╝║  ───  ╚═╗║ ║║  ║  ║╣ ╚═╗╚═╗
╩ ╩╚═╝╩  ╩       ╚═╝╚═╝╚═╝╚═╝╚═╝╚═╝╚═╝

HP (high power) started !!! HSPI nRF24 module initialized SUCCESSFULLY! ############################################################

SPI Frequency		= 16 Mhz
Channel			= 76 (~ 2476 MHz)
Model			= nRF24L01+
RF Data Rate		= 2 MBPS
RF Power Amplifier	= PA_MAX
RF Low Noise Amplifier	= Enabled
CRC Length		= Disabled
Address Length		= 5 bytes
Static Payload Length	= 32 bytes
Auto Retry Delay	= 250 microseconds
Auto Retry Attempts	= 0 maximum
Packets lost on
    current channel	= 0
Retry attempts made for
    last transmission	= 0
Multicast		= Disabled
Custom ACK Payload	= Disabled
Dynamic Payloads	= Disabled
Auto Acknowledgment	= Disabled
Primary Mode		= TX
TX address		= 0xffffffffff
pipe 0 ( open ) bound	= 0xe7e7e7e7e7
pipe 1 ( open ) bound	= 0xc2c2c2c2c2
pipe 2 (closed) bound	= 0xc3
pipe 3 (closed) bound	= 0xc4
pipe 4 (closed) bound	= 0xc5
pipe 5 (closed) bound	= 0xc6
State 1: Bluetooth
State 2: Bluetooth Low Energy
State 3: WiFi
State 4: RC
State 1: Bluetooth
State 2: Bluetooth Low Energy
����������������������������������������������������������������State 4: RC
State 1: Bluetooth
State 2: Bluetooth Low Energy
State 3: WiFi
State 4: RC
State 1: Bluetooth
State 2: Bluetooth Low Energy
State 3: WiFi
State 4: RC
State 1: Bluetooth
State 2: Bluetooth Low Energy
State 3: WiFi
State 4: RC
State 1: Bluetooth
State 2: Bluetooth Low Energy
State 3: WiFi
State 4: RC
State 1: Bluetooth
State 2: Bluetooth Low Energy
State 3: WiFi
```

but nothing happens, bluetooth still works, RC still connects, wifi still has no problem, is there something wrong

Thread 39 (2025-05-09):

download error

M6ct0night, 2025-05-09:
when i try download to software i get Failed to download manifest error i use win11 i try so much driver but nothing changed pls somebody help me

Andrew32151, 2025-05-10:
> when i try download to software i get Failed to download manifest error i use win11 i try so much driver but nothing changed pls somebody help me
>
>

Me too i feel you , if someones help you find out please tag me

Andrew32151

grylcaon, 2025-05-12:
@Andrew32151 hi guys... you must press "boot" button before to connect in the browser... and release the button when "install" messege appears

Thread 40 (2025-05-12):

Don't work. :(

grylcaon, 2025-05-12:
Hi, I have done all the installation and flashing as it is supposed to be... the antennas are installed, but when I plug it in it does not work... it does not turn off the speakers or headphones 2.4 Ghz

I did the basics, module and antennas, still not installed the led or switch.

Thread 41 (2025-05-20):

GPIO missing

jonny190, 2025-05-20:
My board (ESP32-S3-Wroom-1) dosent have some of the GPIO pins can i use other pins ?

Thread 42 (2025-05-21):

YSPI - FAILED

Radioactiverm, 2025-05-21:
So i was finishing the BLE Jammer, i was soldering the indication LED and lastly i snipped off the excess pins. After that the ble jammer is not working at all, status led works but im not sure if it is a software or hardware issue. I'm ussing ESP32-WROOM-32U but it worked flawlessly before i did that step, here are the logs:
ets Jul 29 2019 12:21:46

rst:0x1 (POWERON_RESET),boot:0x13 (SPI_FAST_FLASH_BOOT)
configsip: 0, SPIWP:0xee
clk_drv:0x00,q_drv:0x00,d_drv:0x00,cs0_drv:0x00,hd_drv:0x00,wp_drv:0x00
mode:DIO, clock div:1
load:0x3fff0030,len:1344
load:0x40078000,len:13964
load:0x40080400,len:3600
entry 0x400805f0
####################################################################################################################################

███████ ███████ ██████  ██████  ██████        ██████  ██      ██    ██ ███████      ██  █████  ███    ███ ███    ███ ███████ ██████
██      ██      ██   ██      ██      ██       ██   ██ ██      ██    ██ ██           ██ ██   ██ ████  ████ ████  ████ ██      ██   ██
█████   ███████ ██████   █████   █████  █████ ██████  ██      ██    ██ █████        ██ ███████ ██ ████ ██ ██ ████ ██ █████   ██████
██           ██ ██           ██ ██            ██   ██ ██      ██    ██ ██      ██   ██ ██   ██ ██  ██  ██ ██  ██  ██ ██      ██   ██
███████ ███████ ██      ██████  ███████       ██████  ███████  ██████  ███████  █████  ██   ██ ██      ██ ██      ██ ███████ ██   ██

####################################################################################################################################

                                          Firmware : Combo-Channel-Select (BT-BLE-WiFi-RC)                                 

                        ██████╗ ██╗   ██╗    ███████╗███╗   ███╗███████╗███╗   ██╗███████╗████████╗ █████╗                 
                        ██╔══██╗╚██╗ ██╔╝    ██╔════╝████╗ ████║██╔════╝████╗  ██║██╔════╝╚══██╔══╝██╔══██╗                
                        ██████╔╝ ╚████╔╝     █████╗  ██╔████╔██║█████╗  ██╔██╗ ██║███████╗   ██║   ███████║                
                        ██╔══██╗  ╚██╔╝      ██╔══╝  ██║╚██╔╝██║██╔══╝  ██║╚██╗██║╚════██║   ██║   ██╔══██║                
                        ██████╔╝   ██║       ███████╗██║ ╚═╝ ██║███████╗██║ ╚████║███████║   ██║   ██║  ██║                
                        ╚═════╝    ╚═╝       ╚══════╝╚═╝     ╚═╝╚══════╝╚═╝  ╚═══╝╚══════╝   ╚═╝   ╚═╝  ╚═╝                

####################################################################################################################################

                                                    !Educational purposes only!                                            

                                         https://github.com/EmenstaNougat/ESP32-BlueJammer                                 

                                               I'm not responsible for your actions!                                       

####################################################################################################################################

~~~~~~~~~~~~~~~~~~~~~~~~~~~~~~~~~~~~~~~~~~~~~~~~~~~~~~~~~~~~~~~~~~~~~~~~~~~~~~~~~~~~~~~~~~~~~~~~~~~~~~~~~~~~~~~~~~~~~~~~~~~~~~~~~~~~

╦  ╦╔═╗╔═╗╦       ╔═╗╔═╗╦╦  ╔═╗╔╦╗
╚╗╔╝╚═╗╠═╝║  ───  ╠╣ ╠═╣║║  ║╣  ║║
 ╚╝ ╚═╝╩  ╩       ╚  ╩ ╩╩╩═╝╚═╝═╩╝

!!! SP (standard power) start failure! VSPI nRF24 module could NOT be initialized! #################################################

~~~~~~~~~~~~~~~~~~~~~~~~~~~~~~~~~~~~~~~~~~~~~~~~~~~~~~~~~~~~~~~~~~~~~~~~~~~~~~~~~~~~~~~~~~~~~~~~~~~~~~~~~~~~~~~~~~~~~~~~~~~~~~~~~~~~

╦ ╦╔═╗╔═╗╦       ╔═╗╦ ╦╔═╗╔═╗╔═╗╔═╗╔═╗
╠═╣╚═╗╠═╝║  ───  ╚═╗║ ║║  ║  ║╣ ╚═╗╚═╗
╩ ╩╚═╝╩  ╩       ╚═╝╚═╝╚═╝╚═╝╚═╝╚═╝╚═╝

HP (high power) started !!! HSPI nRF24 module initialized SUCCESSFULLY! ############################################################

SPI Frequency		= 16 Mhz
Channel			= 76 (~ 2476 MHz)
Model			= nRF24L01+
RF Data Rate		= 2 MBPS
RF Power Amplifier	= PA_MAX
RF Low Noise Amplifier	= Enabled
CRC Length		= Disabled
Address Length		= 5 bytes
Static Payload Length	= 32 bytes
Auto Retry Delay	= 250 microseconds
Auto Retry Attempts	= 0 maximum
Packets lost on
    current channel	= 0
Retry attempts made for
    last transmission	= 0
Multicast		= Disabled
Custom ACK Payload	= Disabled
Dynamic Payloads	= Disabled
Auto Acknowledgment	= Disabled
Primary Mode		= TX
TX address		= 0xe7e7e7e7e7
pipe 0 ( open ) bound	= 0xe7e7e7e7e7
pipe 1 ( open ) bound	= 0xc2c2c2c2c2
pipe 2 (closed) bound	= 0xc3
pipe 3 (closed) bound	= 0xc4
pipe 4 (closed) bound	= 0xc5
pipe 5 (closed) bound	= 0xc6
State 1: Bluetooth
Terminal disconnected: NetworkError: The device has been lost.
>

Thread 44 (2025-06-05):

New 3d stl file?

derfx4, 2025-06-05:
Anyone have an updated stl file for the box? The board from DATech Labs seems to have changed a bit. Buttons in different spot and is a different size..??..

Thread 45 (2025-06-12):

Firmware reboots with “core dump flash config is corrupted” on ESP32-WROOM-32 (4 MB)

JRLK0, 2025-06-12:
### Target hardware
| Item | Value |
|------|-------|
| Module | **ESP32‑WROOM‑32 (ESP32‑D0WD‑V3)** |
| Flash size | **4 MB** |
| Board | Generic ESP32 DevKit v3 |

---

### How firmware was flashed
* **Method A – Official Web Flasher**
  <https://esp32‑bluejammerflasher.pages.dev/>
  *Selected* **Combo‑Channel‑Select BT‑BLE‑WiFi‑RC (no OLED)** → flashing *successful* → boot‑loop (see log below).

* **Method B – Manual (esptool)**
```bash
esptool.py erase_flash
esptool.py write_flash -z ^
  0x1000  Combo-Channel-Select_BT-BLE-WiFi-RC.ino.bootloader.bin ^
  0x8000  Combo-Channel-Select_BT-BLE-WiFi-RC.ino.partitions.bin ^
  0xE000  boot_app0.bin ^
  0x10000 Combo-Channel-Select_BT-BLE-WiFi-RC.ino.bin
```
**Both methods give exactly the same reboot loop.**

---

### Serial output (115 200 baud)
```
load:0x3fff0030,len:1344
load:0x40078000,len:13964
load:0x40080400,len:3600
entry 0x400805f0

assert failed: do_core_init startup.c:328 (flash_ret == ESP_OK)

Backtrace: 0x400835bd:0x3ffe3ab0 0x40092d29:0x3ffe3ad0 0x400981a9:0x3ffe3af0
          0x400ded62:0x3ffe3c20 0x40082cd1:0x3ffe3c50 0x40079316:0x3ffe3c90 |<-CORRUPTED

E (334) esp_core_dump_flash: Core dump flash config is corrupted! CRC=0x7bd5c66f instead of 0x0
Rebooting…
```

---

### What I tested
1. `erase_flash` + re‑flash → loop persists
2. Added `boot_app0.bin` → same
3. Custom partition table **with coredump** at 0x150000 → same
4. `erase_region 0x3F0000 0x10000` (last 64 KB) right after flashing → device boots **until next reset**
   ⮕ Indicates firmware is compiled with **Core‑Dump to FLASH** at 0x3F0000; any leftover data triggers the panic on every boot.

---

### Request
Please publish a build with `CONFIG_ESP_COREDUMP_ENABLE=OFF` (or set to UART),
**or** include an empty `coredump` partition at the expected address so the firmware starts on 4 MB modules without manual wipes.

Thanks for the great project — looking forward to testing it! 😊

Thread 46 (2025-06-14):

Can't Flash ESP32 WROOM-32D

srmoska, 2025-06-14:
Can't flash, doing as the instructions said and get the following error:

2025/06/13 20:28:43 [WebView2] Environment created successfully
[BlueFlasher]:[20:28:52]: Flashing firmware to COM5
Error waiting for the command to finish: exit status 2

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

Potiron, 2025-06-22:
Got same issue using W11. Online version is ok!

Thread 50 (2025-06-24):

Clarification about the educational purpose without source code"

BalthasarBH, 2025-06-24:
Hi again,

I noticed some of the previous issues were removed, so I'm trying to ask this as neutrally as possible.

I'm genuinely curious: How is the firmware meant to serve an educational purpose without the source code? Wouldn't transparency about how things are implemented help others understand, learn from, or even improve the project?

I fully respect the decision to keep it closed source – just trying to better understand the philosophy behind it.

Thanks!

EmenstaNougat, 2025-06-24:
Despite being closed-source, the project still serves an educational purpose. It shows that such devices are possible, how the hardware is connected, what components are needed, and what can be achieved with RF modules and an ESP32. Schematics, setup details, and example outputs are openly documented. This helps others learn the concepts, build their own variations, and understand the principles of Bluetooth jamming and RF interference, even without full access to the source code.

Basically just showing such tools exist, everyone knows how a jammer works, it creates noise, pretty simple.
The firmware is intentionally closed-source to prevent misuse. Making it fully open would be like publishing the recipe for a digital handgun, it might start small, but could easily be turned into something far more disruptive. The goal was never to create a tool that could jam entire neighborhoods or be mass-replicated without oversight.

Instead, the project is meant to demonstrate that such jamming is possible, raise awareness about wireless vulnerabilities, and inspire future tools that can detect, prevent, or defend against such attacks. By sharing the hardware setup, concept, and partial insights, but not the full implementation, it encourages learning and experimentation without enabling abuse.

It's a careful balance between education and responsibility. The focus is on building a foundation for better, more secure wireless projects, not mass-distributed interference devices.

Thanks for your understanding! :)

BalthasarBH, 2025-06-25:
Alright, thanks for the clarification.

Even though a truly educational project might benefit from transparency and open discussion, I understand the decision to keep things closed – even if it limits how much people can actually learn from it.

Closing this now – good luck with the binary-only learning model.

Closed 2025-06-25.

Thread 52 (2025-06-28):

No schematics avilable

krasny2k5, 2025-06-28:
I recently discovered this project and I'm interested in experimenting with a BlueJammer device, but currently there are no schematics available, so I don't know how to connect the different components. The PCBs shown on Don Anon's website are sold out and can't be purchased, so I'm stuck.

I've found this alternative PCB: https://www.pcbway.com/project/shareproject/BlueJammer_569e4c8c.html — is it compatible with this project? It would be interesting to include it as an option if it is, since it's something that can actually be purchased.

thanks!

krasny2k5, 2025-06-28:
Sorry, I just saw the list of component connections.

Closed 2025-06-28.

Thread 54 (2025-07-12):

SP (standard power) start failure! VSPI nRF24 module could NOT be initialized!

HuuPhuoc2411, 2025-07-12:
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
I have connected everything correctly and checked many times but still have this error, how to fix it?

concierge-at, 2025-07-27:
same here 3 days i am looking testet 4 nrf moduls wich i use normaly for inverter DTU thy are working the CP2102 works fine firmware run on pressing the boot button i can selct the mode

what is wrong

please give a litte tip to get them work
thank you

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

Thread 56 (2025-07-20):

Request for Arduino (.ino) version or source code

Tecno2P, 2025-07-20:
Hi!

Thanks for your great work on this project — it's very interesting and useful.

I'm trying to learn from this and would love to experiment with it on my ESP32-WROOM-32 board. Could you kindly share the source code (especially the `.ino` or main Arduino-compatible code), or provide guidance on how to build it from scratch?

It would help a lot for educational and testing purposes.

Thanks in advance!

Best regards,
Tecno

EmenstaNougat, 2025-07-20:
Hi, it's closed source

Tecno2P ***@***.***> schrieb am So., 20. Juli 2025, 21:28:

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

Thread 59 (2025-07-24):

Won't start on battery

pdvrk, 2025-07-24:
Hi, I've assembled Elecrow board version with battery and TP4056 and have strange problem. The device will turn on and work perfectly when usb cable is connected to TP4056. I can remove usb cable from TP4056 and device will continue to work on battery. But if I try to turn it on with upper slide switch only on battery, it wont turn on for some reason. I've measured ~4V voltage on slide switch and B+ and B- ports on TP4056, double checked all soldering points, still no luck.

Does anyone have same problem maybe?

pdvrk, 2025-07-24:
The problem was in connection between esp32 and battery ( - ). I've soldered small wire between B- and GND pin on ESP32 and now it works.

pdvrk, 2025-07-24:
I've tried now to resolder TP4056 and kept soldering needle longer on contact, same problem. I also tried to bridge ESP32 GND with TP4056 OUT-, it won't start. It only works on battery power when ESP32 GND is bridged with B- on TP4056.

Do you think that it will help if I cut PH2 connector and solder battery directly on TP4056's B+ and B- ?

EmenstaNougat, 2025-07-24:
That should do it, but it seems like the solder did not reach the bottom of
the PCBs pads.
Could you please take a multimeter and test if it flows from one side on
GND of the pcb anywhere and then both of the TP4056 negative pads?

Marko Racić ***@***.***> schrieb am Do., 24. Juli 2025, 12:24:

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

EmenstaNougat, 2025-07-25:
The tp4056 agent faulty, don't worry.
Both positive in and output on the TP are connected to the same trace,
you'll so if one of those touches the pad, it's fine.
But the negative ones are not, as one of yours does not bave a connection
to the other GND, please try that one out with the negative input of the
JST-PH2 battery connector.

Also, maybe we should hop over to discord for a more reliable chat?

Marko Racić ***@***.***> schrieb am Fr., 25. Juli 2025, 07:49:

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

pdvrk, 2025-07-25:
As I said, at the end I've managed to power on the board with TP4056 B- soldered to one of GND pins on ESP32 with short cable. After that I've noticed that TP4056 won't charge battery (charging led remains ON all the time, with or without battery), so I've ordered a few more TP4056 boards from different supplier and will test again when they arrive. I will let you know the results on Discord.

Thanks for your help and thanks for this great board and firmware!

EmenstaNougat, 2025-07-25:
Keep me updated! :)

Marko Racić ***@***.***> schrieb am Fr., 25. Juli 2025, 13:45:

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

Closed 2025-07-24.

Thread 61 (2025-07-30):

How can i run this on a xiao esp32-c3?

SadCatRRVR, 2025-07-30:
and will i be able to run this without a button?  if not, how do i get a bluetooth jammer on this thing that doesnt need a screen or button

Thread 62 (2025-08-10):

oled case

yourcomputer21, 2025-08-10:
can we get a case v5 stl with the oled screen, third antenna and the added battery?

yourcomputer21, 2025-08-10:
i am currently trying to model one but i am terrible at 3d modeling.

EmenstaNougat, 2025-08-10:
Unfortunately I don't have my first DIY version built with screen or any
free potential space for it

yourcomputer21 ***@***.***> schrieb am So., 10. Aug. 2025,
05:26:

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

Closed 2025-08-11.

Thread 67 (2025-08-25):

Hỗ trợ cho esp32 s3 n16r8

ProdNDT, 2025-08-25:
Xin chào ! Tôi là 1 fan của bạn đến từ VIỆT NAM ! Tôi có 1 vấn đề rất lớn mong được bạn hỗ trợ . Tôi dùng esp32 s3 N16R8 nhưng trên module này
- k có chân gpio 16 để dùng cho HSPI
- không có chân gpio 22,23 cho VSPI (trên s3 là FSPI)
- không có gpio 27 cho led
Bạn có thể hỗ trợ tôi vấn đề đổi các chân spi này sang những chân khác được không ?
Mong nhận được phản hồi từ bạn , cảm ơn bạn đã xem ! Chúc bạn 1 ngày AN YÊN

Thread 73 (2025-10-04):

Power Drop down.

ApacheBlack, 2025-10-04:
Hello and thenk you for your time creating this for the community.
My issue is when i plug the antenas theres is some kind of dopw down voltaje in the circuit. Any idea?
thank you!

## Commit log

2024-08-24 ESP32-BlueJammer by emensta
2025-10-12 ESP32-BlueJammer
    BlueFlasher software not supported anymore! Flash via webflasher or binary files!
2026-03-19 ESP32-BlueJammer
    Added links to related projects for better visibility.
